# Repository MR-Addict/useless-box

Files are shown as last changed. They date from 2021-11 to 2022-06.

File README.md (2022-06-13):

# Useless Box

## 1. Parts needed

### 1.1 3D Printing

There are some parts you need to 3D print yourself, 5 of them totally. You can find them in `3D-File/Stl` folder. You can also modify these parts in `3D-File/Parts` folder if you konw how to use solidworks.

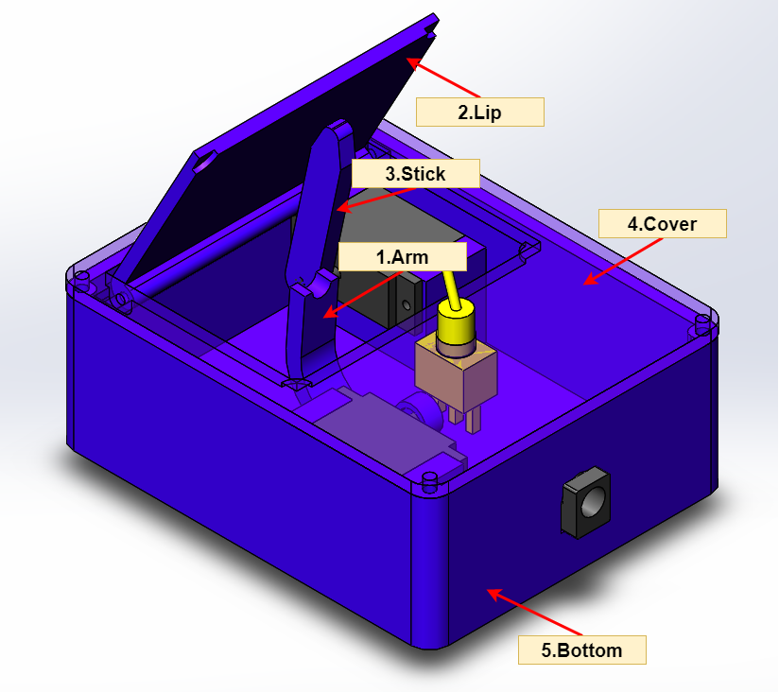
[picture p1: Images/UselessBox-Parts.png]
UselessBox-Parts


### 1.2 Electronics

In this project, I use `Arduino Uno` as my controller, and you also need some other parts as BOM table showing below. Feel free to replace some of them if you are familiar with arduino projects.

| Electronics | quantity | Image |
| :--- | :---: | :---: |
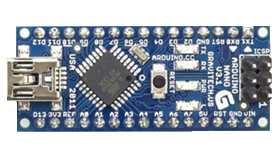
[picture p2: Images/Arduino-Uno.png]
Arduino-Uno
| Arduino Uno | 1 |  |
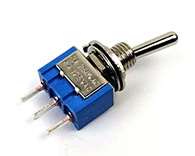
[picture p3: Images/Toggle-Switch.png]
Toggle-Switch
| Toggle Swtich | 1 |  |
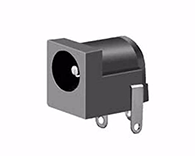
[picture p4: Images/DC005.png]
DC005
| DC-005 Power Socket  | 1 |  |
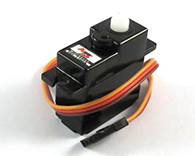
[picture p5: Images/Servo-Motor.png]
Servo-Motor
| HD-1160A Servo Motor | 2 |  |

## 2. Assemble

First you need to wire your electronics referring to below diagram.

> Note that you must apply **5V power** to the circuit if you are wiring like me.

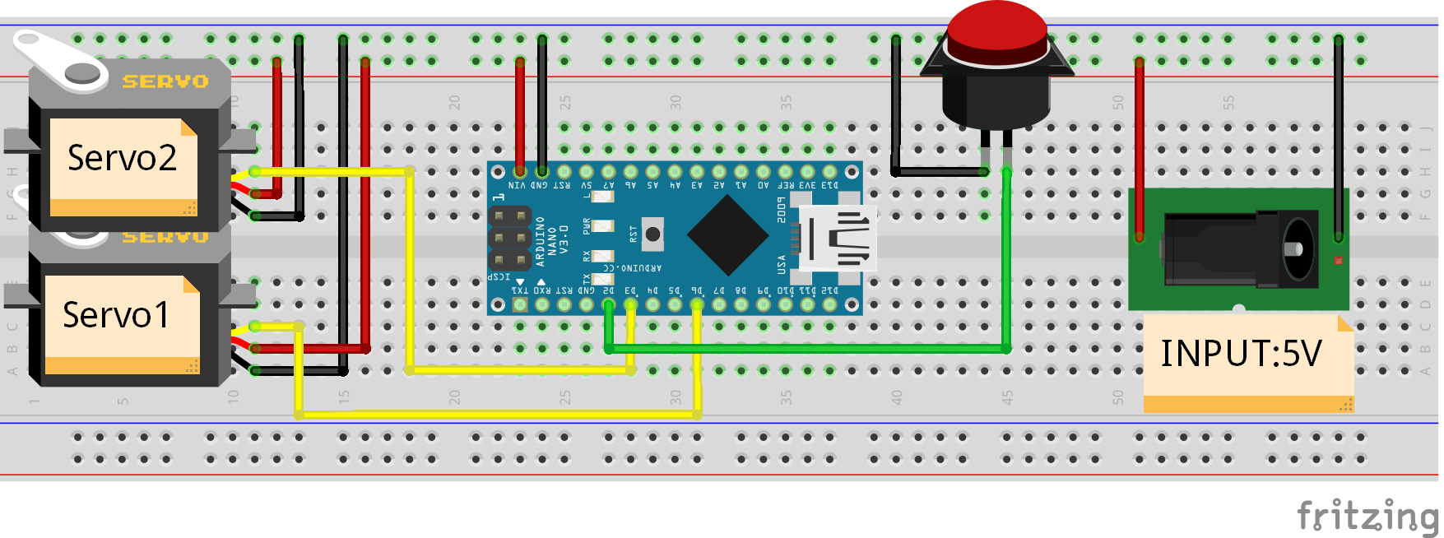
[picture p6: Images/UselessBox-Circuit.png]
UselessBox-Circuit


Then assemble 3D printing parts and wired electronics together.

You can use a longer servo stick instead of using 3D printing **stick** part like I did.

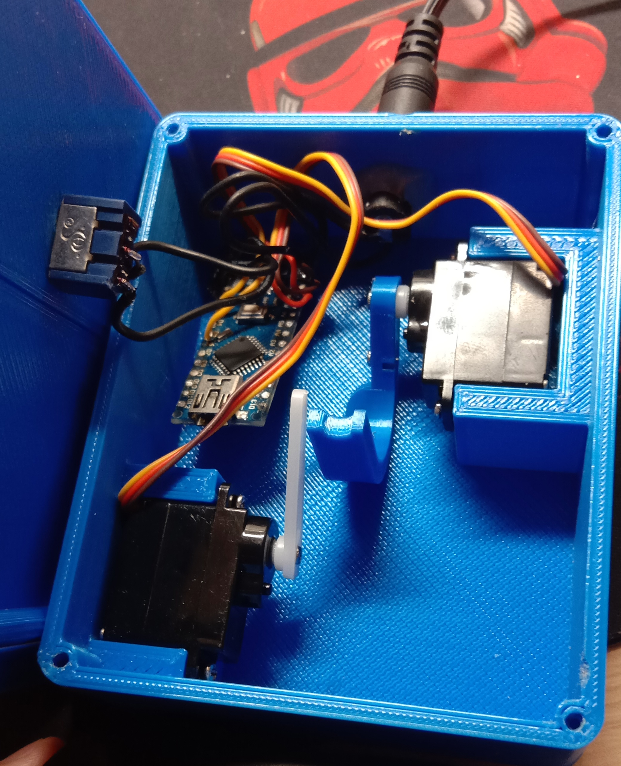
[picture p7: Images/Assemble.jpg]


Finally, upload arduino code to your board and have fun!

## 3. Presentation

https://user-images.githubusercontent.com/75357598/142750349-8485f8f9-0854-4409-b59b-4909fe04149b.mp4

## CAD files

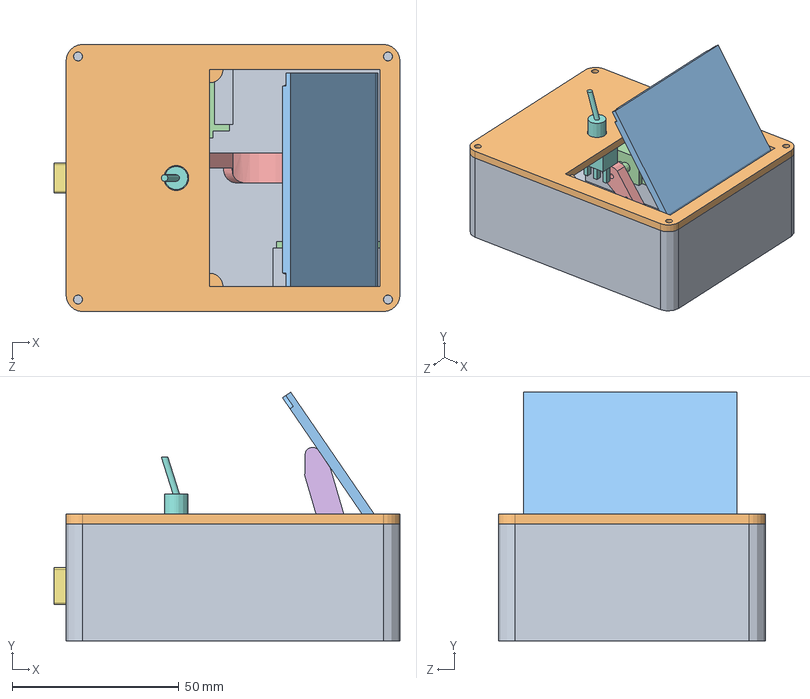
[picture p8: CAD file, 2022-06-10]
3D-File/Assembly/Assemb1.SLDASM
103.6 x 74.5 x 80.0 mm
Bottom
Cover
Lip
Servo x 2
Arm
Stick
DC005
Swtich

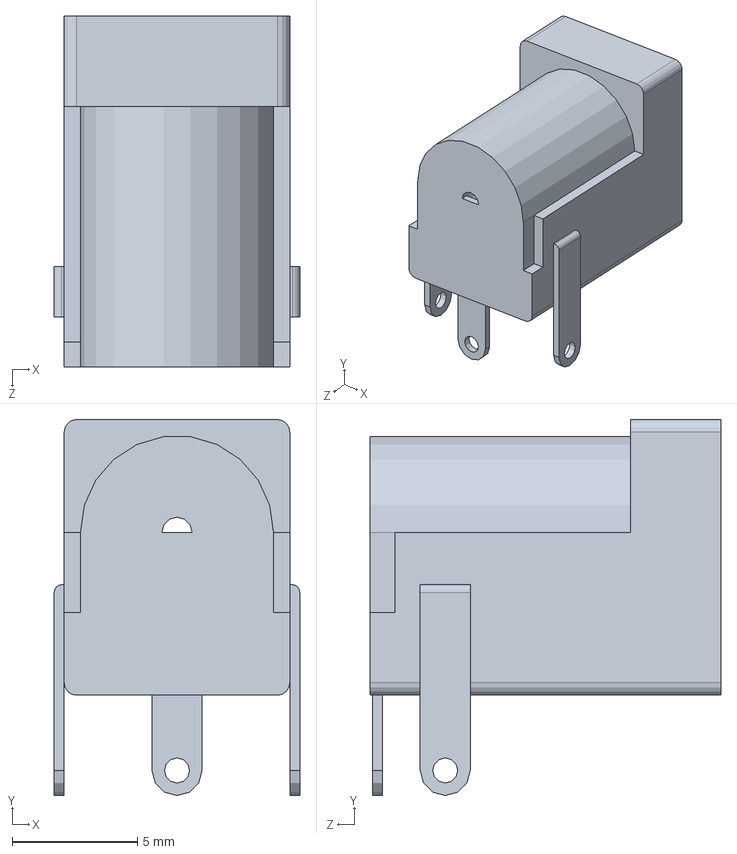
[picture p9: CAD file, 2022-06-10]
3D-File/Parts/DC005.SLDPRT
9.80 x 15.0 x 14.0 mm

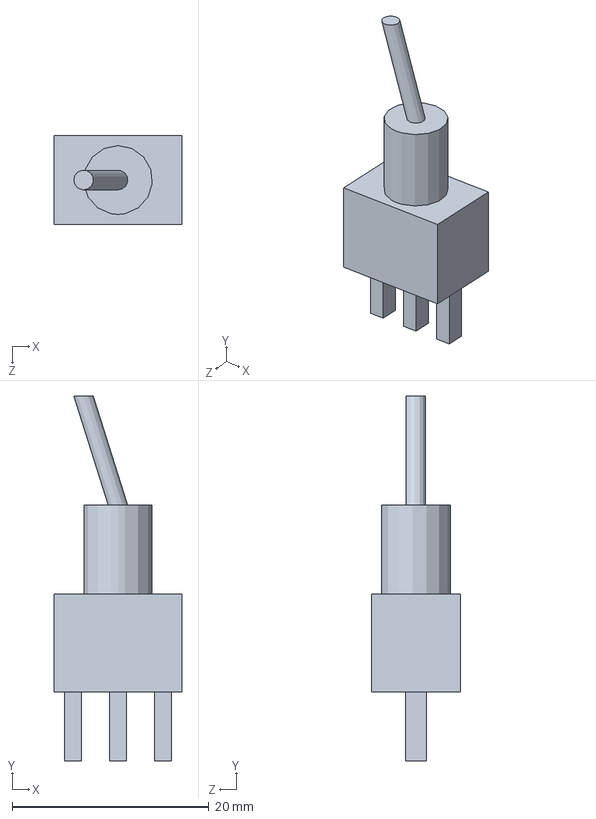
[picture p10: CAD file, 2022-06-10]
3D-File/Parts/Swtich.SLDPRT
13.0 x 37.1 x 9.00 mm

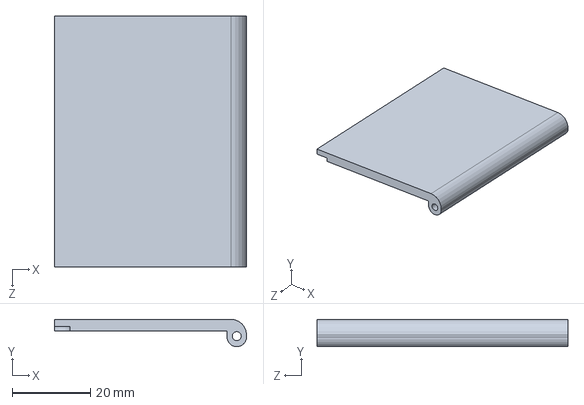
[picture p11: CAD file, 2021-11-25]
3D-File/Parts/Lip.SLDPRT
49.0 x 7.00 x 64.0 mm

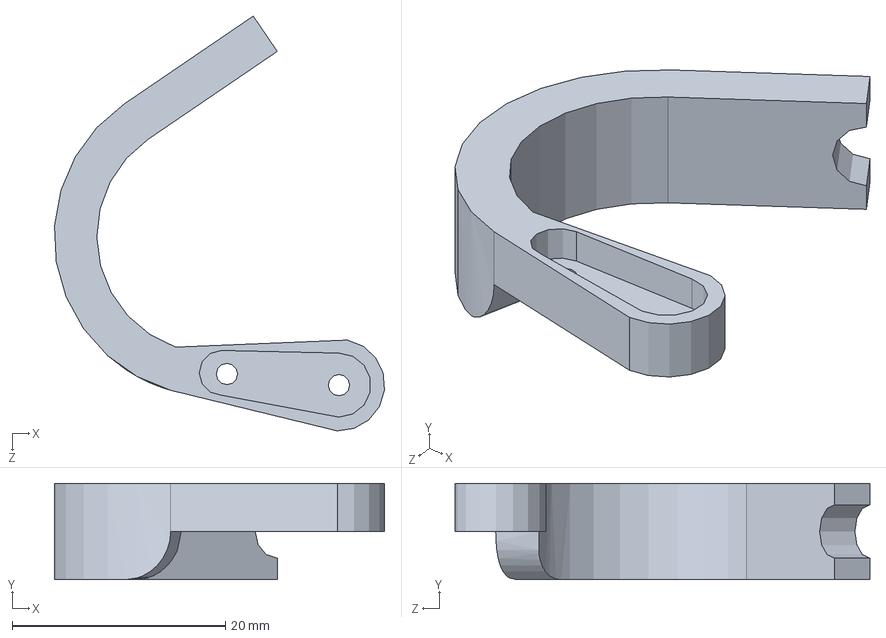
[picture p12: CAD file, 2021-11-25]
3D-File/Parts/Arm.SLDPRT
30.9 x 9.00 x 38.9 mm

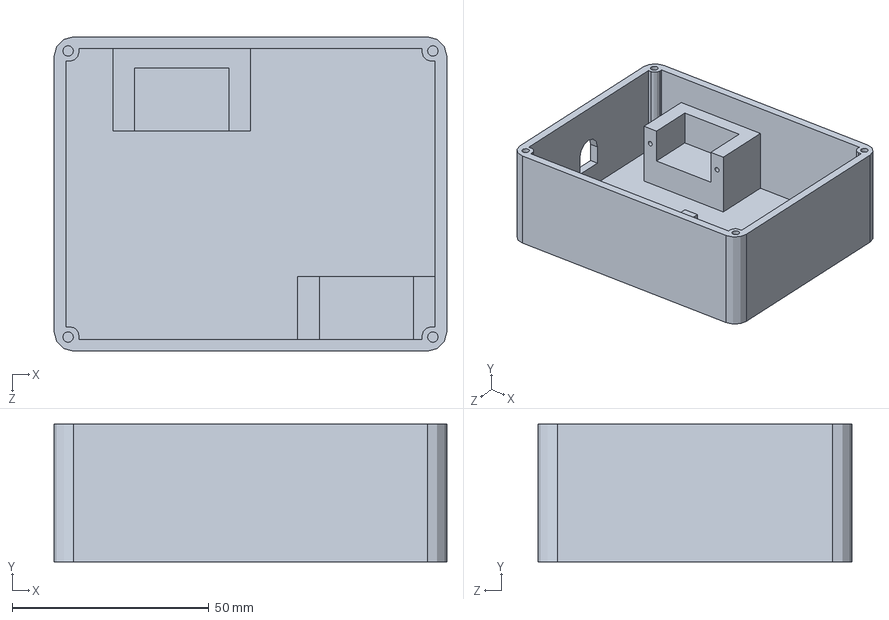
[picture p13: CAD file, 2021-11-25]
3D-File/Parts/Bottom.SLDPRT
100.0 x 35.0 x 80.0 mm

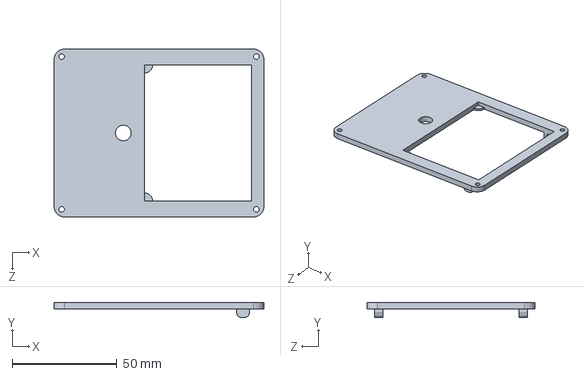
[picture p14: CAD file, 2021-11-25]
3D-File/Parts/Cover.SLDPRT
100.0 x 7.00 x 80.0 mm

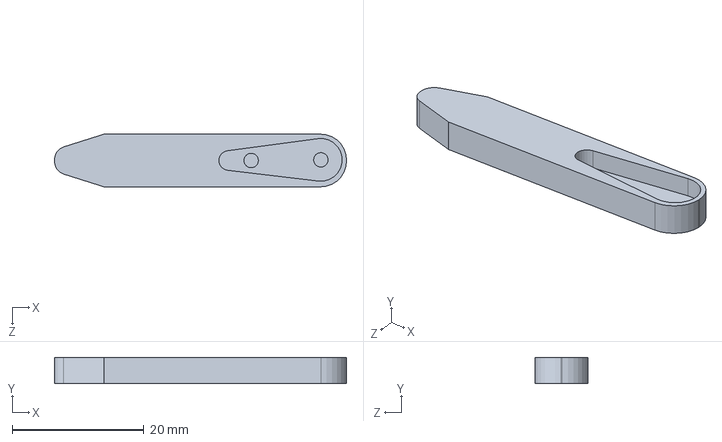
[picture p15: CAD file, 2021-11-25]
3D-File/Parts/Stick.SLDPRT
44.4 x 4.00 x 8.00 mm

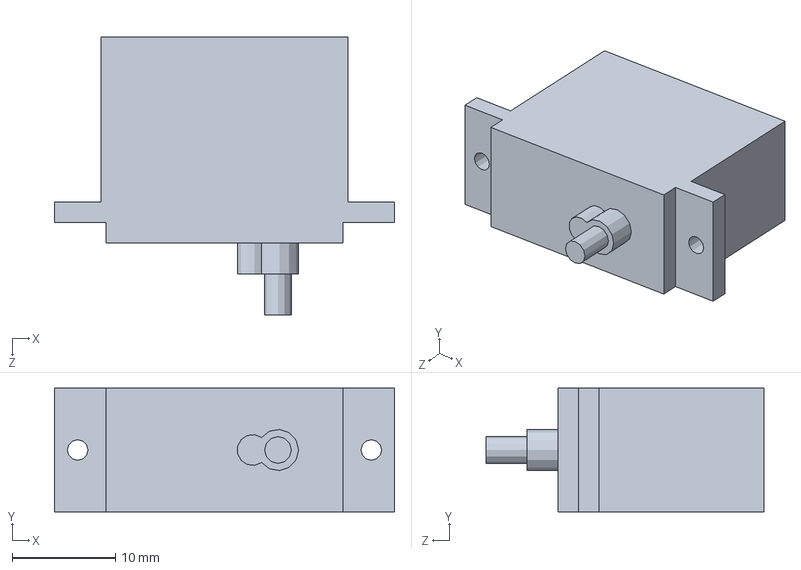
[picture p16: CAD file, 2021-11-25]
3D-File/Parts/Servo.SLDPRT
33.0 x 12.0 x 27.0 mm

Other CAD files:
3D-File/Stl/Arm.stl
3D-File/Stl/Bottom.STL
3D-File/Stl/Cover.stl
3D-File/Stl/Lip.STL
3D-File/Stl/Stick.STL

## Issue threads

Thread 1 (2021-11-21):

Requesting more info on the Usless Box

macalikm, 2021-11-21:
Hi,
I downloaded and printed the Useless Box stl files from Thingiverse.
Is there any more documentation for the project than what's listed here?
I'm assuming that 123.ino is an Arduino Sketch to run the whole thing.

Which Arduino did you use?
What is the second servo  and stick for? (they aren't shown in the documentation)
Is there a wiring diagram?
Is there a parts and construction layout?

Would you like any help in documenting the project?

Cheers
Mike

MR-Addict, 2021-11-21:
Hi @macalikm ,thanks for downloading and trying my this useless box project.

I'm sorry about not adding enough information about my project.
I have done some changes about this github repository.

The electronic parts you need is shown in **Fritzing diagram**.

I know that you have printed the 3D parts,so just assemble them.
About the second servo stick, that's in **3D File/stick.stl**.
I find that you can just use a **longer servo stick** to replace this part,that's a better choice.

The code sketch is in **Code/Useless_Box.ino**.
I'm sorry about not deleting some initializing files,that's why 123.ino exits.😅

Finally, I would be very happy if you can do me a favor on documenting this project.

Hugs
Cael

macalikm, 2021-11-21:
Cael,
Thanks for getting back to me. I just ordered some servos and an Arduino
Nano.
After the parts arrive, I'll take careful notes as I build it.
Once I get everything working smoothly, I'll try to write a mini "How To "(
in ENglish) and send it to you.

By the way, Nice work on the 3D printed parts.

Thanks,
Mike

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

MR-Addict, 2021-11-22:
Hi Mike
It's great to hear from you so quickly.

I'm so glad to hear that you like this project and spend time helping me to write a document.
You can contact me at any time if you encounter any problems while building it.

I really appreciate your help.

Best
Cael

macalikm, 2021-11-25:
Hi Cael,

I see that you updated the README.MD on your github. The photo is very
helpful!

The servos that I ordered for the Useless Box arrived in the post yesterday.
I got MG90S micro servos from Tower Pro.
The servos  don't quite fit in the mounting areas in Bottom-stl.
One mounting space isn't deep enough for the servo housing.
And neither of them had openings to accommodate the wires on  these servos.
The ribbon cable for this brand comes out the side of the housing.
None of the horns that come with my servos fit in the Arm that you designed.
I have Solidworks Student Edition, so that would be pretty simple to fix

Would it be possible for you to send or add the Solidworks SLDPRT (part)
files to your Thingiverse or git post?
There is a Solidworks assembly file (1.SLDASM) on thingiverse, but it
doesn't contain the part files.

I might also like to attempt adding mounting holes for the Arduino Nano or
ProMini and a battery compartment.

I did have a chance to wire-up a breadboard and run the Arduino sketch.
The way that the motors move makes sense to me now.

I'm keeping good notes on  the progress, and will send you a Documentation
when it's done.
I'll also include and part files that I come-up with and include
descriptions in the Docs.

Thanks Again,
MIke

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

MR-Addict, 2021-11-25:
Hi Mike

I have updated Solidworks Files to git.
Now you can download and modify these parts.

I'm sorry about that trouble.
The reason Bottom Part isn't fit your motor, mostly  is that I used black smaller ones.
Did you use the blue ones, and I think that kind of servo motor is more popular.
So feel free to modify them.

If you got more problems, just contact me, and I will do my best.

By the way, I really thanks for what you are doing for documenting.

Best
Cael

macalikm, 2021-11-25:
Hi Cael,

Thanks for the files.
Here's a Pic of the servos that I have.
[image: TowerProMG90S.jpg]

I tested them out on an arduino with your sketch and everything seems to
work well.
I have a Nano ordered that should fit in the bottom-stl.
I recall that you suggested trying some  different sized sticks..

It's a holiday here, so I won't be able to get to the 3dPrinter until next
week.
I'll let you know how it goes.

Thanks Again,
Mike

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

macalikm, 2021-12-08:
Hi Cael,
I didn't forget about helping with the Docs.
I tried building a Useless Box with the servos that I have, and nothing fit.
The servos are much deeper than the originals.
I redrew some of the parts in Solid works, but haven't printed them yet.

I think that I'm just going to get some of the smaller Black Servos and
build it per your original drawings.
I'm keeping good notes and still plan on sending you a mini How to when I'm
done.

Best Wishes,
Mike

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

MR-Addict, 2022-06-13:
Hi Mike

I'm really sorry for not replying  to you in time.

I‘m very grafteful if you're still working on documenting my project and I'd love to put your efforts to this project whenever you finished.

If you like I can invite you to this repository so that you can push your commits. We can also discuss some details about 3D design, codes, wiring and etc. I would be very happy if we can do this together.

I'm looking forward to hearing from you!

Best Wishes,
Cael

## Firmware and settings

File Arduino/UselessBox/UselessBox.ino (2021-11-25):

#include <Servo.h>

//initlize the servo and the switch
Servo myservo1;
Servo myservo2;

const uint8_t Button = 2;

//modify the servo beginning value to fit your servo position in box
const uint8_t Servo1BeginPos = 15;
const uint8_t Servo2BeginPos = 2;

void setup() {
  pinMode(Button, INPUT_PULLUP);

  myservo1.attach(6); //servo1 attch to the back arm
  myservo2.attach(3); //servo2 attch to the front arm
  myservo1.write(Servo1BeginPos);
  myservo2.write(Servo2BeginPos);
}

void loop() {
  int Time_Delay;
  if (digitalRead(Button)) {
    //back arm go up and open the cover
    Time_Delay = random(1, 3);
    for (int i = myservo1.read(); i <= 90; i += Time_Delay) {
      myservo1.write(i);
      delay(15);
    }
    //1/3 percent that the box arm would pretent to push the switch
    if (random(1, 10) % 3 == 0) {
      Time_Delay = 2;
      for (int i = myservo2.read(); i <= 45; i += Time_Delay) {
        myservo2.write(i);
        delay(15);
      }
      delay(500);
      Time_Delay = 1;
      for (int i = myservo2.read(); i >= Servo2BeginPos; i -= Time_Delay) {
        myservo2.write(i);
        delay(15);
      }
      Time_Delay = 2;
      for (int i = myservo1.read(); i >= Servo1BeginPos; i -= Time_Delay) {
        myservo1.write(i);
        delay(15);
      }
      delay(700);
      Time_Delay = 2;
      for (int i = myservo1.read(); i <= 90; i += Time_Delay) {
        myservo1.write(i);
        delay(15);
      }
    }
    //front arm go up and push the switch
    Time_Delay = random(1, 3);
    for (int i = myservo2.read(); i <= 65; i += Time_Delay) {
      myservo2.write(i);
      delay(15);
    }

    //front arm go down first
    Time_Delay = random(1, 3);
    for (int i = myservo2.read(); i >= 2; i -= Time_Delay) {
      myservo2.write(i);
      delay(15);
    }
    //then back arm go down
    Time_Delay = random(1, 3);
    for (int i = myservo1.read(); i >= 15; i -= Time_Delay) {
      myservo1.write(i);
      delay(15);
    }
    //1/4 percent that the box pretend to show up to peep your movement
    if (random(1, 10) % 4 == 0) {
      delay(1000);
      Time_Delay = 1;
      for (int i = myservo1.read(); i <= 90; i += Time_Delay) {
        myservo1.write(i);
        delay(5);
      }
      delay(1000);
      Time_Delay = 1;
      for (int i = myservo1.read(); i >= 15; i -= Time_Delay) {
        myservo1.write(i);
        delay(15);
      }
    }
  }
}
